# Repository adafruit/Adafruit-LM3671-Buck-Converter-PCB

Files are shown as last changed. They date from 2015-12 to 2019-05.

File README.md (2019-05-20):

## Adafruit LM3671 Buck Converter PCB
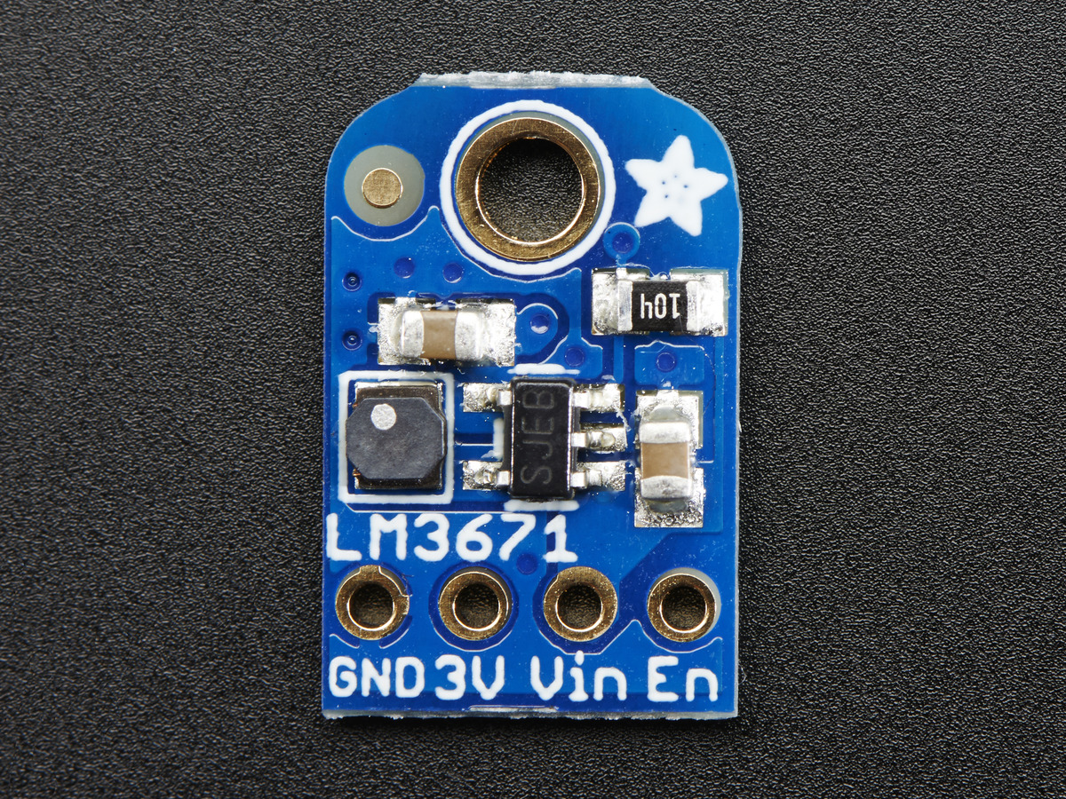
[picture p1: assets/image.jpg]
<a href="http://www.adafruit.com/products/2745"><br/>
Click here to purchase one from the Adafruit shop</a>

Your power supply problems just got SUPER SOLVED! This 3.3V Buck Converter Breakout board is great for supplying power to low voltage circuits from a single Li-Ion cell battery or USB power.  This chip provides up to 600-mA load current across the entire input voltage range of 3.5 to 5.5V.  Great for your portable project, we made this "pin compatible" with the LM1117-3.3V TO-220 chip so you can swap it in for better performance (90-95% efficiency!) There's also an ENable pin, tie it low to shut down the output completely.

There's a 2-MHz fixed-frequency in PWM mode and PFM mode extends the battery life by reducing the current during light load or standby operation.

PCB files for Adafruit LM3671 Buck Converter. The format is EagleCAD schematic and board layout
- https://www.adafruit.com/product/2745

### License

Adafruit invests time and resources providing this open source design, please support Adafruit and open-source hardware by purchasing products from [Adafruit](https://www.adafruit.com)!

All text above must be included in any redistribution

Designed by Limor Fried/Ladyada for Adafruit Industries.
Creative Commons Attribution/Share-Alike, all text above must be included in any redistribution. 
See license.txt for additional information.

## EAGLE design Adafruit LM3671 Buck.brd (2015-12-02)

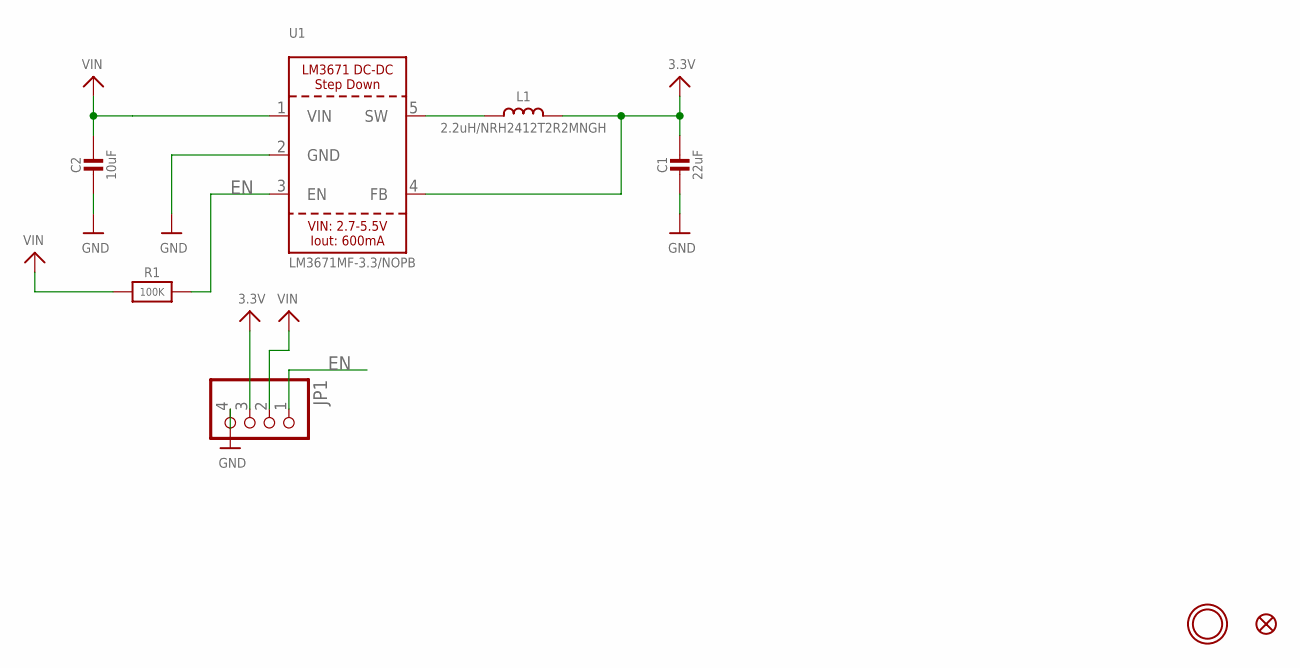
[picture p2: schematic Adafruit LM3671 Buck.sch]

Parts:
C1: 22uF; 0805-NO
C2: 10uF; 0805-NO
FID1: FIDUCIAL""; FIDUCIAL_1MM
JP1: HEADER-1X4ROUND; 1X04_ROUND
L1: 2.2uH/NRH2412T2R2MNGH; INDUCTOR_TAIYOYUDEN_NRH2412T
R1: 100K; 0805-NO
U1: LM3671MF-3.3/NOPB; SOT23-5
U$9: MOUNTINGHOLE2.5; MOUNTINGHOLE_2.5_PLATED

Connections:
3.3V: C1.1, JP1.3, L1.2, U1.4 (FB)
EN: JP1.1, R1.2, U1.3 (EN)
GND: C1.2, C2.2, JP1.4, U1.2 (GND)
unnamed: L1.1, U1.5 (SW)
VIN: C2.1, JP1.2, R1.1, U1.1 (VIN)

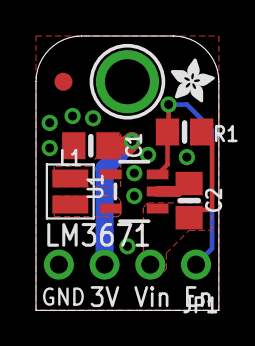
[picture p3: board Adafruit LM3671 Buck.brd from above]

Board: 2 copper layers, 10.2 x 15.2 mm, 10 parts (1 on the bottom side), 5 nets.

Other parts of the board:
U$10: PCBFEAT-REV-040
U$11: ADAFRUIT_2.5MM

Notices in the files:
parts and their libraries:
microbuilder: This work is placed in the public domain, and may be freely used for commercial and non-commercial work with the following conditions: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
